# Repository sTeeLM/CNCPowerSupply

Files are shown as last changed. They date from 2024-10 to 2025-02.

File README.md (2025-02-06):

## 一个隔离四通道的数控+程控可调低波纹直流电源 ##
### 介绍 ###
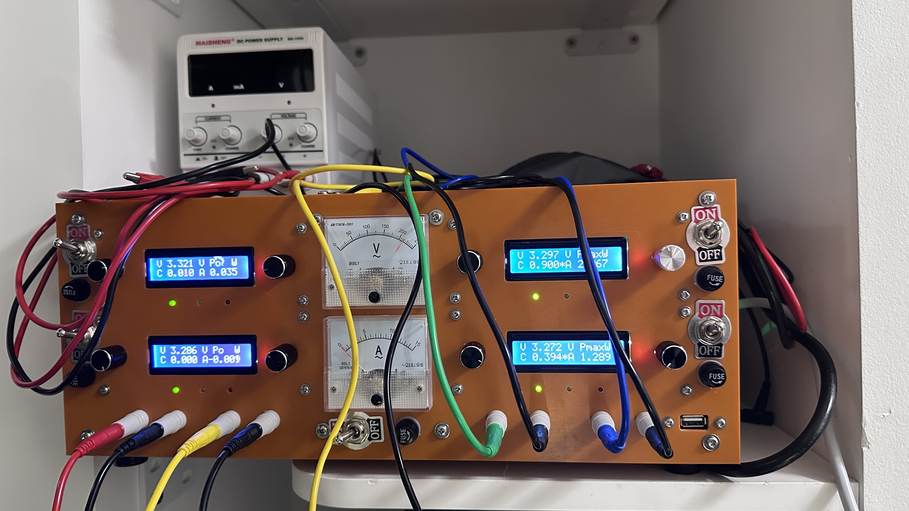
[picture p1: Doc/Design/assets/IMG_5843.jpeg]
完成图

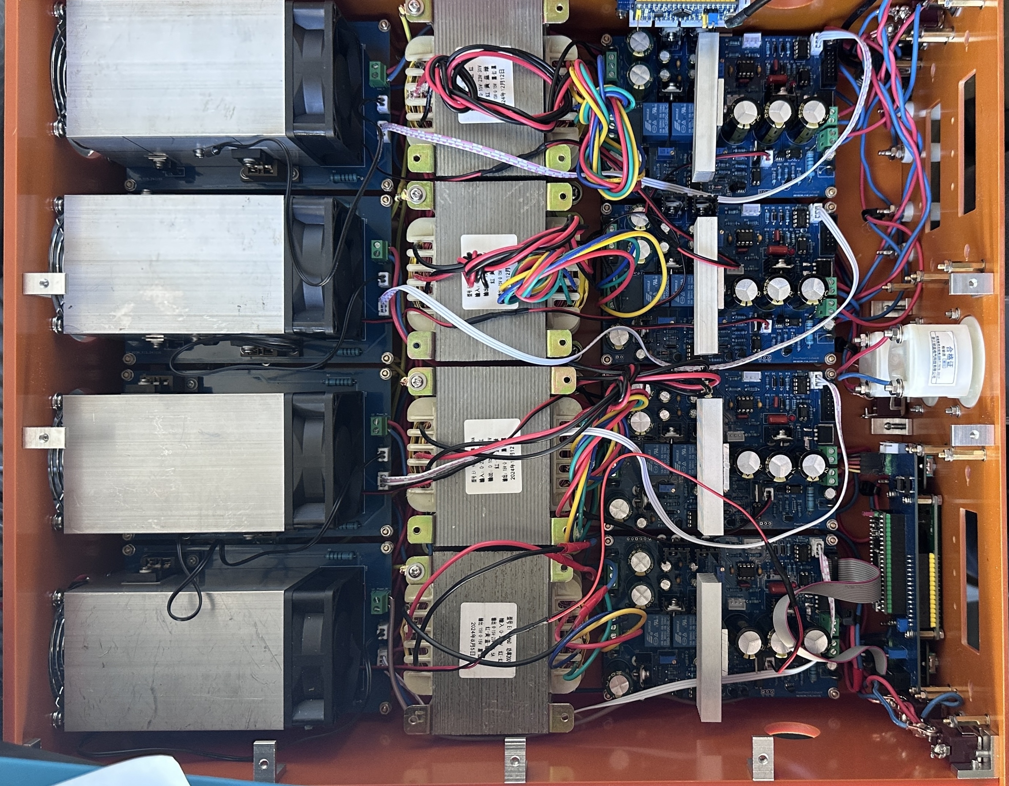
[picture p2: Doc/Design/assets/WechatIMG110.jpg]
内部构造


每通道最大输出电压30V，电流5A，波纹小于1mV，各通道独立可串联或者并联，可以通过USB远程用电脑程序化控制。
由于采用了原始的线性降压设计，带着4个200VA的变压器，加上外壳、散热器重量，所以很笨重。
外壳采用酚醛树脂制作，第一次折腾AutoCAD，加上审美不在线，做出来浓浓的苏联风。
成本量产500RMB以内，单个制作1000RMB左右，市面上类似电源一个2000～4000RMB不等。

### 主要功能 ###
1. 4路直流隔离，每路最大输出30V+5A，可长时间工作
2. 预设4挡电压电流值，可修改
3. 自动风扇控制，上下阈值可设置
4. 高耗散功率自动断开防烧毁
5. USB电脑远程控制和编程扩展
6. 在线校正和上位机校正

### TODO ###
1. 前置开关电源而不是变压器，以波纹换重量优化。
2. 完成USB上位机的控制程序，内嵌Python解释器。
3. 更好的校正设计甚至是自动校正。

## A CNC DC Power Supply with 4 independent channel ##
The maximum output voltage of each channel is 30V, the current is 5A, and the ripple is less than 1mV. all channels can be connected in series or parallel.
It can be programmed and controlled remotely via USB.
Because it uses an original linear step-down design with a 200VA transformer, it is extremely bulky. The shell is made of phenolic resin and has a strong Soviet style.

### TODO ###
1. use switching power supply plus linear convertor instead of the transformer for weight optimization.
2. Complete the control program on the USB host computer and embed the Python interpreter.
3. Better calibration design or even automatic calibration.

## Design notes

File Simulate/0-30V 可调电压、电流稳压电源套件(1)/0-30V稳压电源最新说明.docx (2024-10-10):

0-30V 可调电压、电流稳压电源安装使用说明书

这是一个高品质的连续可调稳压电源，电压调整范围为0-30V，还包含了一个电流输出限制电路，有效地控制最大输出电流从 2毫安到3安连续可调，这个特色让这个稳压电源成为电路实验不可或缺的利器， 它可以把电流限制在实验电路的典型最大工作电流，大胆地开启电源，不用担心因故障或安装错误造成大电流破坏实验电路。

技术规格：

输入电压：24V 交流（最大）

输入电流：3A（最大）

输出电压：0-30V 连续可调

输出限制电流：2mA-3A 连续可调

输出电压纹波：0.01%（最大）

电路特点：

全部直插元件，安装、维修简单方便；

输出电压易于调整；

输出电流限制状态由 LED 指示；

当输出电流超过限制电流时自动转为恒流模式， 对超负载或故障提供完全保护。

元件清单：

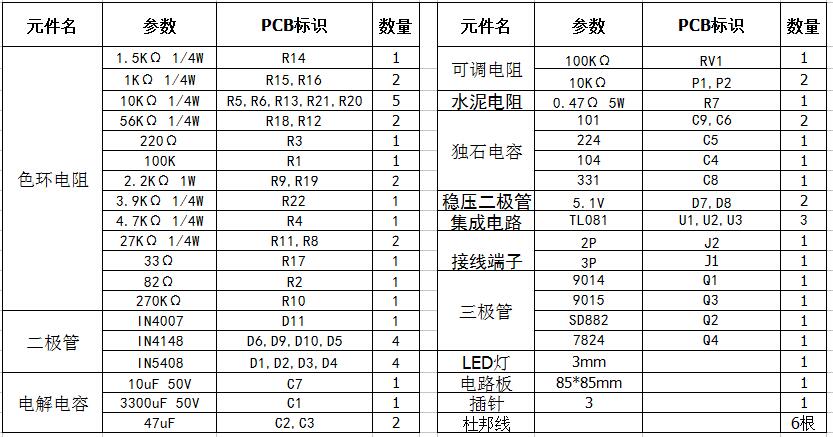
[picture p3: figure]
元件清单

安装步骤：

1.按照 PCB 标示安装电阻、二极管等，电阻安装前务必用万用表核对阻值确保正确，二极管注意型号、安装方向。

2. 依照从小到大、从低到高的原则安装其他元件。

3. 注意集成电路的安装方向，电位器可直接安装在板上， 也可用配套的插座及连线引到面板安装。

4.全部安装完毕，仔细检查无误后，即可通电试机，通电前务必确保 Q4（D1047）安装了足够大面积的散热片，散热片需与电路

绝缘

电路调整：

左边电位器用于电流调节，右边电位器用于电压调节。

1.将电压调整电位器设在最小位置(逆时针旋到最小) ，调整 RV1（100K 可调电阻） ，使输出电压为0V 即可（调整中可能会出现负电

压并且数值很小，请使用数字万用表进行） 。最大输出电压不需调整，使用 24V 交流输入时，最大输出电压约为 31V 左右。

2.电流标定：使用合适的负载电阻接在输出端，比如 10 欧（确保功率足够） ，电流电位器旋至最大，电压电位器旋至最小，开机

慢慢增加电压至 1V，逆时针调整电流电位器至发光管刚刚发亮，此时电路限制电流为 0.1A，标记下此时电位器的位置。依次调整至

2V、5V、10V、20V、30V 等数值，即可标定不同的输出电流，计算公式为：I=U/ R，如使用 10 欧负载，当 U 为 30V 时，I=3A

（最大输出） 。也可以换用其他阻值负载电阻，但务必注意功率足够并散热良好。

注意事项：

1.变压器输出电压为单 24V 或双 12V（中心头空置） ，功率可按需选择，如需满载输出（30V3A） ，变压器功率应在 90W 以上。

注意：本电路必须使用 24V 交流输入，不能使用直流输入。

2.输出调整管 D1047 安装散热器时需注意与电路绝缘，因本电路属于线性稳压电源， 调整管耗散功率比较大， 务必保证 D1047

散热良好。

3.电源制作属于大电流高电压电路，如安装有误可能造成危险，请务必认真核对元件型号并正确安装。

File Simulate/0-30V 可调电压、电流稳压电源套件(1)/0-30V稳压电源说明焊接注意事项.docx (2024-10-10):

0-30V 可调电压、电流稳压电源安装使用说明书

这是一个高品质的连续可调稳压电源，电压调整范围为0-30V，还包含了一个电流输出限制电路，有效地控制最大输出电流从 2毫安到3安连续可调，这个特色让这个稳压电源成为电路实验不可或缺的利器， 它可以把电流限制在实验电路的典型最大工作电流，大胆地开启电源，不用担心因故障或安装错误造成大电流破坏实验电路。

技术规格：

输入电压：24V 交流（最大）

输入电流：3A（最大）

输出电压：0-30V 连续可调

输出限制电流：2mA-3A 连续可调

输出电压纹波：0.01%（最大）

电路特点：

全部直插元件，安装、维修简单方便；

输出电压易于调整；

输出电流限制状态由 LED 指示；

当输出电流超过限制电流时自动转为恒流模式， 对超负载或故障提供完全保护。

元件清单：安装步骤：

元件清单
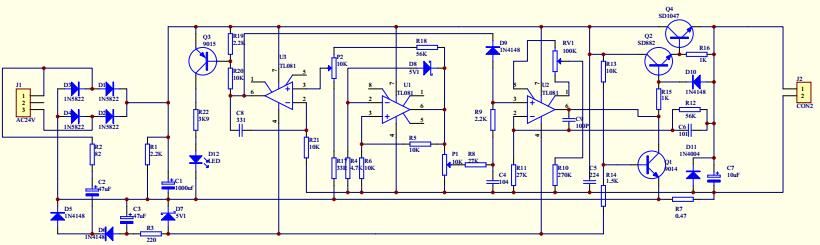
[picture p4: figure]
电路图

1.按照 PCB 标示安装电阻、二极管等，电阻安装前务必用万用表核对阻值确保正确，二极管注意型号、安装方向。

2. 依照从小到大、从低到高的原则安装其他元件。

3. 注意集成电路的安装方向，电位器可直接安装在板上， 也可用配套的插座及连线引到面板安装。

4.全部安装完毕，仔细检查无误后，即可通电试机，通电前务必确保 Q4（D1047）安装了足够大面积的散热片，散热片需与电路

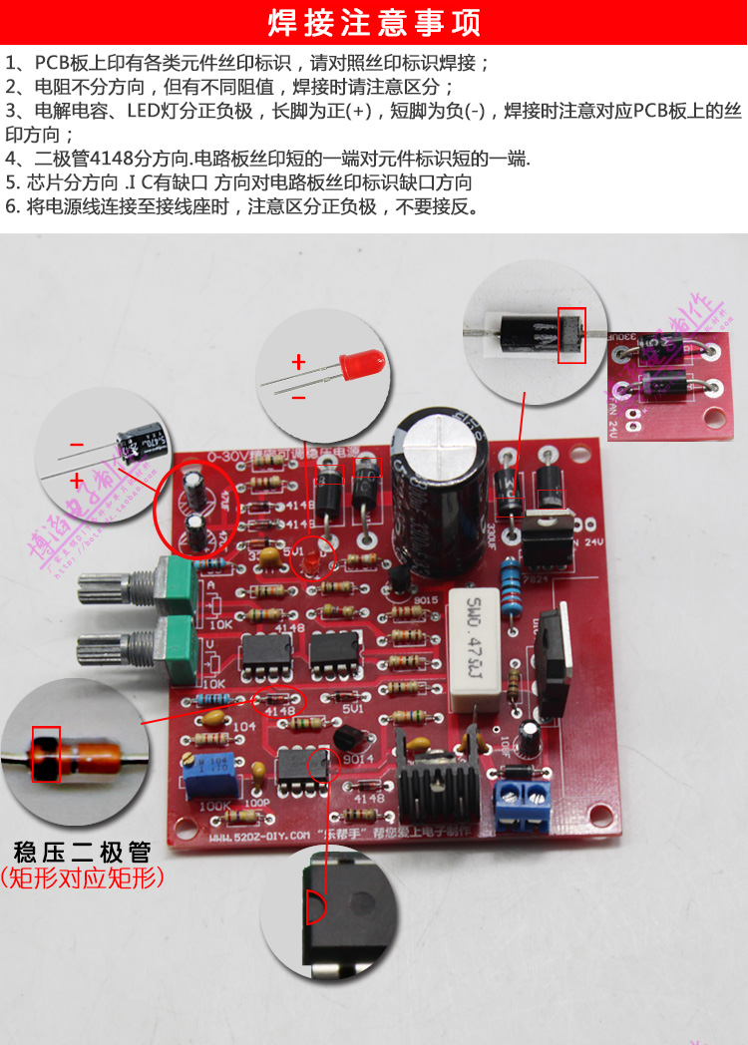
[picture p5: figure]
详情_06

绝缘

电路调整：

左边电位器用于电流调节，右边电位器用于电压调节。

1.将电压调整电位器设在最小位置(逆时针旋到最小) ，调整 RV1（100K 可调电阻） ，使输出电压为0V 即可（调整中可能会出现负电

压并且数值很小，请使用数字万用表进行） 。最大输出电压不需调整，使用 24V 交流输入时，最大输出电压约为 31V 左右。

2.电流标定：使用合适的负载电阻接在输出端，比如 10 欧（确保功率足够） ，电流电位器旋至最大，电压电位器旋至最小，开机

慢慢增加电压至 1V，逆时针调整电流电位器至发光管刚刚发亮，此时电路限制电流为 0.1A，标记下此时电位器的位置。依次调整至

2V、5V、10V、20V、30V 等数值，即可标定不同的输出电流，计算公式为：I=U/ R，如使用 10 欧负载，当 U 为 30V 时，I=3A

（最大输出） 。也可以换用其他阻值负载电阻，但务必注意功率足够并散热良好。

注意事项：

1.变压器输出电压为单 24V 或双 12V（中心头空置） ，功率可按需选择，如需满载输出（30V3A） ，变压器功率应在 90W 以上。

注意：本电路必须使用 24V 交流输入，不能使用直流输入。

2.输出调整管 D1047 安装散热器时需注意与电路绝缘，因本电路属于线性稳压电源， 调整管耗散功率比较大， 务必保证 D1047

散热良好。

3.电源制作属于大电流高电压电路，如安装有误可能造成危险，请务必认真核对元件型号并正确安装。

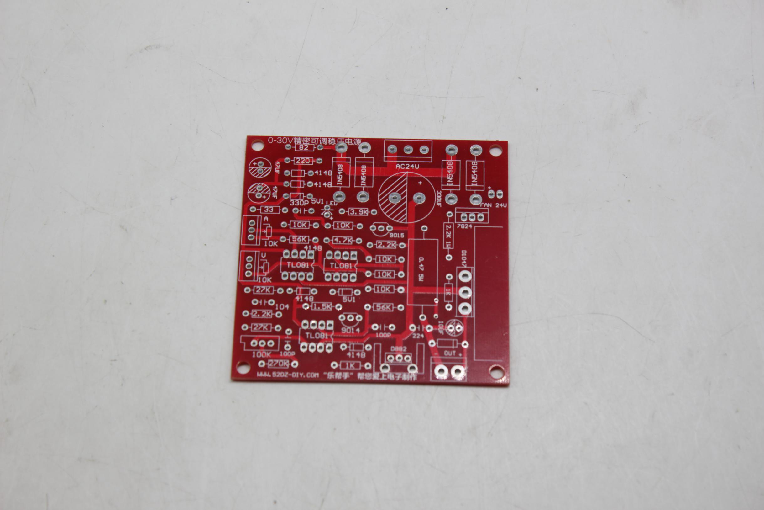
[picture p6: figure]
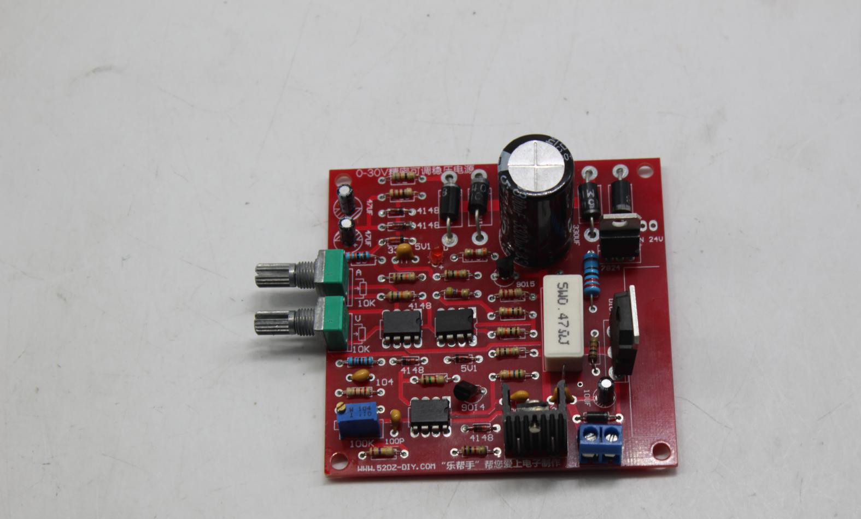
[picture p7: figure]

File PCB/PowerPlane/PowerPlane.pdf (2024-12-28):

Designator | Value | Name | Description | Quantity
C1, C6, C9, C10, C21 | 104 | | Capacitor | 5
C2, C13 | 471 | BBC | Capacitor | 2
C3, C8, C20 | 3300uF | 35V | Polarized Capacitor (Radial) | 3
C4, C7, C19 | 470uF | 25V | Polarized Capacitor (Radial) | 3
C5, C11 | 220uF | 16V | Polarized Capacitor (Radial) | 2
C12 | 153 | BBC | Capacitor | 1
C14 | 100uF | 50V | Polarized Capacitor (Radial) | 1
C15, C16, C17 | 2200uF | 63V | Polarized Capacitor (Radial) | 3
C18 | 47uF | 50V | Polarized Capacitor (Radial) | 1
D1 | | CC | Typical RED GaAs LED | 1
D2, D3, D10, D11 | | 1N5408 | 1 Amp General Purpose Rectifier | 4
D4, D5, D6, D7, D8, D9, D12, D13 | | 1N4007 | 1 Amp General Purpose Rectifier | 8
D14, D15 | | 1N4728 | Zener Diode | 2
Q1 | | TL431 | TL431 | 1
Q2 | | F4905S | P-Channel Power MOSFET | 1
Q3, Q5 | | TIP41 | NPN Bipolar Transistor | 2
Q4, Q6 | | S8550 | PNP Bipolar Transistor | 2
Q7 | | 2N5551 | NPN Bipolar Transistor | 1
Q8, Q9 | | S8050 | NPN Bipolar Transistor | 2
R1, R40, R41 | 2.7K | | Resistor | 3
R2, R24, R26 | 2K | | Resistor | 3
R3, R6, R10, R20, R21, R23, R28, R30, R37, R39, R45, R46 | 10K | | Resistor | 12
R4, R7, R8, R14, R15, R17, R43, R44 100R | | | Resistor | 8
R5 | 5K | | Potentiometer | 1
R9, R12 | 1M | | Resistor | 2
R11 | 6.8K | | Resistor | 1
R13, R27, R29 | 1K | | Resistor | 3
R16 | 3K | | Resistor | 1
R18, R36 | 100K | | Resistor | 2
R19 | 33K | | Resistor | 1
R22, R25 | 4.7K | | Resistor | 2
R31 | 330K | | Resistor | 1
R32 | 30K | 2W | Resistor | 1
R33 | 4.3K | 2W | Resistor | 1
R34 | 150K | | Resistor | 1
R35 | 56K | | Resistor | 1
R38, R42 | 10K | | Potentiometer | 2
U1, U9, U19 | | EL817C | EL817C | 3
U2, U22 | | L7812 | L7812 | 2
U3 | | L7805 | L7805 | 1
U4 | | TL082 | TL082 | 1
U5 | | LM393 | LM393 | 1
U6, U8 | | POT-3P | POT-3P | 2
U7 | | POWER3 | Power Connector 3 | 1
U10 | | L7912 | L7912 | 1
U11 | | L7905 | L7905 | 1
U12 | | POWER4 | Power Connector 3 | 1
U13, U14 | | SDR12VDCSLC | SDR12VDCSLC | 2
U15 | | FAN | FAN | 1
U16 | | KBU1010 | KBU1010 | 1
U17, U20 | | POWER2 | POWER2 | 2
U18 | | REG3 | REG2 | 1
U21 | | DC3-12P | DC3-12P | 1
U23 | | LM358 | LM358 | 1

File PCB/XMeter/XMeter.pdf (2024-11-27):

Line # | Designator | Value | Description | Quantity
| C1, C2, C6, C12, C15, C16, C18, C20, C22 | 104 | Capacitor | 9
| C3, C4, C7, C9 | 105 | Capacitor | 4
| C5, C11, C21 | 100uF | Polarized Capacitor (Radial) | 3
| C8, C10 | 226 | Capacitor | 2
| C13 | 474 | Capacitor | 1
| C14, C17, C19 | 106 | Capacitor | 3
| D1 | | 1 Amp General Purpose Rectifier | 1
| D2 | | Typical RED GaAs LED | 1
| D3 | | Typical RED GaAs LED | 1
| D4 | | Typical RED GaAs LED | 1
| Q1 | | PNP Bipolar Transistor | 1
| R1, R2, R21, R23, R24, R25 | 10K | Resistor | 6
| R3, R4, R18 | 0R | Resistor | 3
| R5 | 10K | Potentiometer | 1
| R6, R8, R15, R16 | 47K | Resistor | 4
| R7 | 43K | Resistor | 1
| R9, R11 | 20K | Resistor | 2
| R10 | 150K | Resistor | 1
| R12, R13, R14, R22 | 4.7K | Resistor | 4
| R17 | 270K | Resistor | 1
| R19 | 1K | Potentiometer | 1
| R20 | 30K | Resistor | 1
| R26 | 100 | Resistor | 1
| R27, R28, R29 | 1K | Resistor | 3
| U1 | | REF5020 | 1
| U2 | | REF5025 | 1
| U3, U4 | | DAC8571 | 2
| U5, U9 | | OPA2335 | 2
| U6 | | REF3230 | 1
| U7 | | LCD1602 | 1
| U8 | | DC3-12P | 1
| U10 | | STC89C516CORE | 1
| U11 | | CODEKEY | 1
| U12 | | ADS1115 | 1
| U13 | | BEEPER | 1
| U14 | | CODEKEY | 1
| U15 | | SG3030CM | 1
| U16 | | SERIAL4P | 1
| U17 | | AT24C02 | 1

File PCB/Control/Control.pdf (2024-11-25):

Line # | Designator | Value | Name | Description | Quantity
| D1 | | CN0 | Typical RED GaAs LED | 1
| D2 | | CN2 | Typical RED GaAs LED | 1
| D3 | | CN1 | Typical RED GaAs LED | 1
| D4 | | CN3 | Typical RED GaAs LED | 1
| R1, R2, R3, R4 | 1K | | Resistor | 4
| R5 | 0R | 500mA Fuse | Resistor | 1
| R6 | 10K | | Resistor | 1
| R7, R8 | 20R | | Resistor | 2
| U1, U3, U5, U7 | | ISO6721B | ISO6721B | 4
| U2, U4, U6, U8 | | SERIAL4P | SERIAL4P | 4
| U9 | | STM32F103CCORE | STM32F103CCORE | 1
| U10 | | USB-X254 | USB-X254 | 1
| U11 | | 74HC4052 | 74HC4052 | 1
| U12 | | CTLDBG | CTLDBG | 1

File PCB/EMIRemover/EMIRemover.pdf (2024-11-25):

Line # | Designator | Value | Name | Description | Quantity
| R1, R5, R6 | | 10D431K | 10D431K | 3
| R2, R4, R7 | | B5G600L | B5G600L | 3
| C1, C4 | 472 | 400V | Capacitor | 2
| C2, C3, C5 | 474 | 275V | Capacitor | 3
| U1, U2 | | HB9500-3P | HB9500-3P | 2
| R3 | 560K | 2W | Resistor | 1
| L1, L2 | | SQ3324/15A/10mH | SQ3324 | 2

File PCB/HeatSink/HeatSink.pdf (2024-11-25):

Line # | Designator | Value | Name | Description | Quantity
| Q1, Q2 | | TIP3055 | NPN Bipolar Transistor | 2
| U1 | | NTC | NTC | 1
| U2 | | POWER2 | POWER2 | 1
| U3 | | REG3 | REG2 | 1
| R1, R2 | 200 | 1W | Resistor | 2
| R3, R4 | 0.22R | 5W | Resistor | 2
| R5 | 0.4R | 35W | Resistor | 1

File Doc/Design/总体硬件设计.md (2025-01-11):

## 关键问题以及解决思路

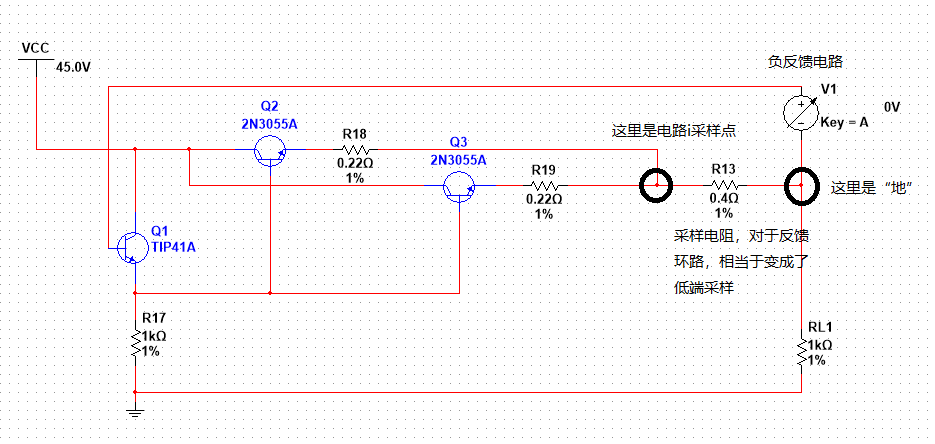
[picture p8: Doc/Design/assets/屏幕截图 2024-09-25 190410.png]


通过一段时间的实践（折腾），研究了很多参考设计，体会到一个可调线性电源，面临的核心设计问题是：
- 反馈运放需要对调整三极管输出足够高的，接近输出电压的高压来让调整三级管正常工作，从而选型困难或者设计复杂或者贵（> 44V的很少了，同时很难做到即要高压同时又要高精密）
- 如果采用性能更好的高端电流采样（低端采样，采样电阻在地一侧，输出电压会有误差），需要引入仪表放大器，、差分放大器又让设计变得更复杂，同时反馈环路引入放大器很容易不稳定
- 调整三极管耗散功率在输入输出电压差很高时，不可接受（烧毁）

问题1、2解决思路如上图（其中为了说明思路，用可变电压源代替电压反馈环和电流反馈环），反馈控制电路整个“架在”高端，输出电压的高端变成了反馈控制电路的地，反馈输出一个小控制电压，叠加在大的输出电压上作为整个反馈，这样完全不需要任何高压运放和高压仪表放大器之类的器件，用低端器件就可以搭（反馈输出参考地是输出电压高端，所以只需要正负几V、非轨到轨的运放都能用），由于降低了运放的电压要求，我们可以找到又便宜，精度又高的器件来用。同时电流采样和反馈很直观和简单，原来复杂的宽范围可变的高共模电压下电流采样电阻两端差分电压精确测量问题，变成了非常简单的对地测采样电阻的电压问题，唯一缺点是电压反馈就变得更稍微复杂一些，因为对运放来讲要求输入电压接近地并且大于地，而对输出电压直接采样的话，无论如何都做不到（采样结果一定小于输出电压，也就是地）。当然也可以加一个反向放大器，让负电压变正电压，但是在反馈环路中加放大器，是个需要很小心的事情，一不小心就震荡了。

这个缺点的克服方法非常巧妙，我们把输出电压加一个小的（本设计是2.5V）参考电压偏移，然后再做电压采样，巧妙的构造一个负反馈环：深度负反馈时候，根据虚短，可以得知(x+2.5)b=x+c，对，你没看错，采样反馈加在运放的正输入而不是负输入

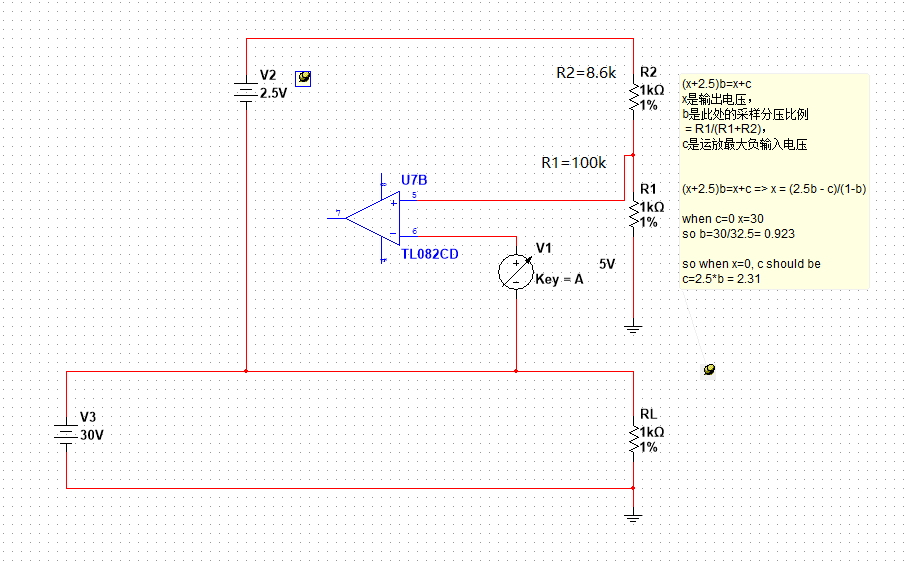
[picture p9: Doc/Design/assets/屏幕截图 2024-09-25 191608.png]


问题3的解决思路，是根据输出电压自动分段选择输入电压，在输出电压较低时候采用较低的输入电压，从而降低输入输出的压差和耗散功率，减少发热，我们直接采用2个继电器来切换各档输入电压。

## 总体硬件设计

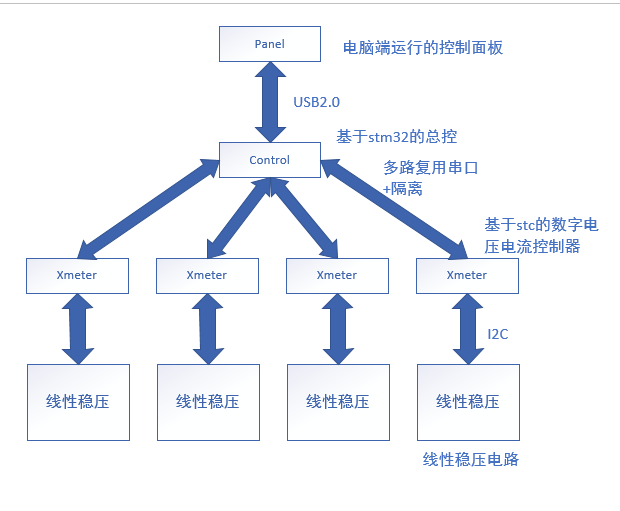
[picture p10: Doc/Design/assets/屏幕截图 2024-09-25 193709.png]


剩下的工作，无非是简单的嵌入式设计，只需要简单的数电基础，C语言写写程序，用AutoCAD设计下外壳（我们用成本更低的电木板材拼接，不用3D打印，整个外壳制造过程就是板材上钻孔，尽量避免铣槽，降低成本）

从单通道扩展到多通道很简单粗暴，如上图直接复制四份，然后加一个总控，每一个channel之间做好直流隔离就好（直接用4套变压器，并且和总控的串口通讯通过隔离芯片），从而这四个channel可以串联用、并联用。
在极低波纹下，可以达到600W的输出功率，拼出最高120V乘5A或者30V乘20A的输出。

做4路还有一个好处是，可以同时提供多种不同的电压输出，极大方便了我们调试各种板子（例如同时提供3.3\5V\正负12V这样的组合，直接给电脑主板供电）。

数控意味着可以在panel处通过电脑连USB控制4路电源，甚至使用程序扩展（例如写一段锂电池充电程序，先恒流再恒压等等）

## 选型

为啥XMeter用8051（STC的），总控用STM32，就是因为这两个片子我屯多了，没有经过仔细的考虑，就是手里有什么用什么。

## 制作后体会 ##
1. 模电基本功很重要，不少坑都踩在基本功上，无论是运放一不小心就震荡，还是MOS打开电压过低就会内阻狂飙，还是三极管工作参数的计算、二极管的各种骚操作，电阻电容延时时间的计算，这些东西比数电有趣太多了。
2. 设计一时爽，制造火葬场：面向制造环节的各种要素（可测性、量产、成本等）做设计才是真正有挑战的地方，细节众多，迭代慢，不是很确定是不是真的可以AI搞定一切。跨领域知识储备要求也很高，要在这些既跨领域，又依赖的要素之间做权衡，对知识的深度和精确度，以及复杂问题解决能力都是很高的挑战。如果训练模型的话，怎么把一个一个经验case（特别是怎么排查故障）都总结成样本，可能是最难的吧。
设计一时爽，制造火葬场的另一层含义是，小制作都是打样很爽，批量制造是个体力活，我不喜欢重复性工作，本质上是手工焊接做4套电源，焊四遍，每遍4张PCB，还需要手工拧螺丝、接线组装焊好的PCB板和其它杂碎零件，更别提各种故障排查了。
4. 基本原则一定要遵守、一定要养成好习惯，例如：
* 做好面包板、焊好PCB上电前，一定检查焊点和元件位置，有插槽检查插槽。
* 上电前一定用万用表打一下VCC和地。
* 上电异常，断电后没有追到原因，排除问题之前坚决不能再次上电，"试一试"都不要。
* 追查问题一定从最简单猜测开始追，先检查基础假设。
* 凡有反常必有妖，不符合预期一定要追查到底。

基本上本次制作过程中所有翻过的车，踩过的坑，白白烧掉的元件，浪费的时间和返工，如果严格遵守上述5条，99%都可以避免。

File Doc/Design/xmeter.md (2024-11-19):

## 交互总体原则 
1. 交互符合直觉，逻辑前后尽量一致（我也曾经是个产品经理。。）  
两个按钮的用法，尽量按照符合直觉操作习惯设计  
1. mod：短按是模式切换，旋转是电压调整、数值粗调  
1. set：短按是数值选定，旋转是电流调整、数值精调  
1. 长按是特殊功能  

## 事件
|名称|含义|
|--|--|
250ms| 时钟脉冲250ms
1s| 时钟脉冲1s
Mu|Mod Up  
Md| Mod Down  
Ms| Mod Short Press  
Ml| Mod Long Press  
Mc| Mod Clock wise  
Mcc| Mod Counter Clock wise  
Su| Set Up  
Sd| Set Down  
Ss| Set Short Press  
Sl| Set Long Press  
Sc| Set Clock wise  
Scc| Set Counter Clock wise  
MSs| Mod+Set Press  
MSl| Mod+Set Long Press  
OVER_HEAT|过热  
OVER_PD|过载  
TEMP_HI| 温度超过阈值  
TEMP_LO| 温度低于阈值  
EV_TIMEO| 超时  

## 功能1 XMeter
**主功能，电压、电流、功率、温度显示、设置、过载保护**
### Main
**显示V、C、P**
|事件|动作|
|--|--|
Ms|进入PickV  
Ss|进入PickC  
Ml|进入Aux0  
Sl|进入Param功能  
MSs|进入校准功能  
Mc/Mcc|进入SetV  
Sc/Scc|进入SetC  
250ms|从ADC更新一遍计数并刷新LCD  
OVER_HEAT|关闭电源，打开风扇，进入OverHeat  
OVER_PD|关闭电源，进入OverPd  
TEMP_HI|开风扇  
TEMP_LO|关风扇  

### Aux0
**显示Vi、Pd**
|事件|动作|
|---|---|
250ms|从ADC更新一遍计数并刷新LCD  
Ms| 回到Main  
EV_TIMEO| 回到Main  
Mc/Mcc| Aux0/Aux1切换  
Sc/Scc| Aux0/Aux1切换  
OVER_HEAT| 关闭电源，打开风扇，进入OverHeat  
OVER_PD| 关闭电源，进入OverPd  
TEMP_HI| 开风扇  
TEMP_LO|关风扇  

### Aux1
**显示T、Fan**
|事件|动作|
|---|---|
250ms| 从ADC更新一遍计数并刷新LCD
Ms| 回到Main
EV_TIMEO| 回到Main
Mc/Mcc| Aux0/Aux1切换
Sc/Scc| Aux0/Aux1切换
OVER_HEAT| 关闭电源，打开风扇，进入OverHeat
OVER_PD| 关闭电源，进入OverPd
TEMP_HI| 开风扇
TEMP_LO|关风扇

### PickPreV
**选择预设置电压**
|事件|动作|
|---|---|
250ms| 从ADC更新一遍计数并刷新LCD
Mc/Mcc| 切换预设电压
Ms| 设置预设电压并返回Main **特殊不符合约定的设计，但是更符合直觉**
OVER_HEAT| 关闭电源，打开风扇，进入OverHeat
OVER_PD| 关闭电源，进入OverPd
TEMP_HI| 开风扇
TEMP_LO| 关风扇
EV_TIMEO| 放弃设置回到Main

### PickPreC
**选择预设值电流**
|事件|动作|
|---|---|
250ms| 从ADC更新一遍计数并刷新LCD
Sc/Scc| 切换预设电流
Ss| 设置预设电流并返回Main
OVER_HEAT| 关闭电源，打开风扇，进入OverHeat
OVER_PD| 关闭电源，进入OverPd
TEMP_HI| 开风扇
TEMP_LO|关风扇
EV_TIMEO| 放弃设置回到Main

### SetV
**设置电压**
|事件|动作|
|---|---|
250ms| 从ADC更新一遍计数并刷新LCD
Mc/Mcc| 粗粒度设置电压（100mV）
Sc/Scc| 细粒度设置电压（小数最末有效数字，最小1mV）
Ms| 设置预设电压并返回Main
EV_TIMEO| 放弃设置回到Main
OVER_HEAT| 关闭电源，打开风扇，进入OverHeat
OVER_PD| 关闭电源，进入OverPd
TEMP_HI| 开风扇
TEMP_LO|关风扇

### SetC
**设置电流**
|事件|动作|
|---|---|
250ms| 从ADC更新一遍计数并刷新LCD
Mc/Mcc| 粗粒度设置电流（100mA）
Sc/Scc| 细粒度设置电流（小数最末有效数字，最小1mA）
Ss| 设置预设电流并返回Main
EV_TIMEO| 放弃设置回到Main
OVER_HEAT| 关闭电源，打开风扇，进入OverHeat
OVER_PD| 关闭电源，进入OverPd
TEMP_HI| 开风扇
TEMP_LO| 关风扇

### OverHeat
**过热状态**
|事件|动作|
|---|---|
250ms| 从ADC更新一遍计数并刷新LCD
Ss| 开始一次检测，如果温度低于TEMP_LO发送EV_TIMEO消息
EV_TIMEO| 打开电源并回到Main
TEMP_HI| 开风扇
TEMP_LO| 关闭风扇

### OverPd
**过载状态**
|事件|动作|
|---|---|
250ms| 从ADC更新一遍计数并刷新LCD
Ss| 打开电源并回到Main
TEMP_HI| 开风扇
TEMP_LO| 关闭风扇

## 功能2 参数设置 Set Param
> 辅助功能，设置各种参数，交互逻辑是分为4个大功能块  
> 每个功能块入口都可以通过Sl回到XMeter主界面  
> 功能块入口Ms切换功能块，Ss数值设置  
> 这样设计本质是把一个大的平铺线性向导，分割成了几个子向导  
> 避免了一次设置必须要全部经过一遍的囧境  
1. 保护相关的参数设置
2. 预设电压
3. 预设电流
4. 其他杂项参数
### Fan（功能块入口1）
**风扇温度上下限**
|事件|动作|
|---|---|
Mc/Mcc| 开启温度上限（以0.5 C）
Sc/Scc| 关闭温度下限（以0.5 C）
Ss| 设置温度上下限，并进入OverProtect
Ms| 进入SelPreV
Sl| 回到Main

### 过载保护OverProtect
**过载保护温度和功率**
|事件|动作|
|---|---|
Mc/Mcc| 过载保护温度（以0.5 C）
Sc/Scc| 最大耗散功率（以0.5 w）
Ss|  设置参数，并回到Fan

### SelPreV（功能块入口2）
**切换预设电压**
|事件|动作|
|---|---|
Mc/Mcc| 切换预设电压index
Sc/Scc| 切换预设电压index
Ss| 选定index并进入SetPreV
Ms| 进入SelPreC

### SetPreV
**设置预设电压**
|事件|动作|
|---|---|
Mc/Mcc| 粗调电压（100mV）
Sc/Scc| 精调电压（小数最末有效数字，最小1mV）
Ss| 设置并回到SelPreV

### SelPreC （功能块入口3）
**切换预设电流**
|事件|动作|
|---|---|
Mc/Mcc| 切换预设电流index
Sc/Scc| 切换预设电流index
Ss| 选定index进入SetPreC
Ms| 进入Beeper

### SetPrevC
**设置预设电流**
|事件|动作|
|---|---|
Mc/Mcc| 粗调电流（100mV）
Sc/Scc| 精调电流（小数最末有效数字，最小1mA）
Ss| 设置并回到SelPreC

### Beeper （功能块入口4）
**开关Beeper**
|事件|动作|
|---|---|
Mc/Mcc| Beeper On/Off切换
Mc/Mcc| Beeper On/Off切换
Ss| 设置Beeper并进入Fan设置
Ms| 回到Fan，但是不保存设置

## 功能3 Calibration
**辅助功能，校准功率平面的零值和最大值**
**过载保护功能完全关闭**
**风扇完全关闭**
三个阶段：  
1. 物理调整（手工）
2. 参数标定（手工）
3. 参数计算（自动）
阶段1可调节的几个物理电位器:  
- A. 电压反馈分压电位器(控制电压最大值)
- B. 两个三段电压继电器对应的电位器（控制2个切换输入电压）
### CalPhyVoltage
**电压物理调整，调整目标**
- 三段电压继电器正常工作（调节B）
- 电压DAC在0xFFFF对应输出30V（调节A，在0x0000可能输入的是负数，没关系）
- 用笔记录在输出0V的时候，输入电压万用表读数

|事件|动作|
|---|---|
Mc/Mcc| 粗调电压电位器读数（16LSB）
Sc/Scc| 精调电压电位器读数（1LSB）
Ss| 切换到CalVoltageZero
### CalVoltageZero
**标定输出电压零点**
- 调整到电压输出0V，按下Ss

|事件|动作|
|---|---|
Mc/Mcc| 粗调电压电位器读数（16LSB）
Sc/Scc| 精调电压电位器读数（1LSB）
Ss| 记录输出电压0点时的ADC参数（和*耗散电压ADC参数*），切换到CalVoltageMax
### CalVoltageMax
**标定输出电压最大值**
- 调整到电压输出30V，按下Ss

|事件|动作|
|---|---|
Mc/Mcc| 粗调电压电位器读数（16LSB）
Sc/Scc| 精调电压电位器读数（1LSB）
Ss| 记录输出电压最大点参数，*电压DAC设置为5V输出档*，切换到CalCurrentZero
### CalCurrentZero
**标定输出电流零点**
- 短路输出，调整到电流输出0A，按下Ss

|事件|动作|
|---|---|
Mc/Mcc| 粗调电流电位器读数（16LSB）
Sc/Scc| 精调电流电位器读数（1LSB）
Ss| 记录输出电流为0时的参数(电流DAC)，切换到CalPhyCurrentMax
### CalCurrentMax
**标定输出电流最大值**
- 短路输出，调整到电流输出5A，按下Ss

|事件|动作|
|---|---|
Mc/Mcc| 粗调电流电位器读数（16LSB）
Sc/Scc| 精调电流电位器读数（1LSB）
Ss | 记录输出电流为5A时的参数(电流DAC)，切换到InputVoltageDiss
### InputVoltageDiss
**输入耗散电压读数**
- 输入耗散电压读数
Mc/Mcc| 粗调电压输入（100mV）
Sc/Scc| 精调电压读数（1mV）
Ss | 记录输出电压为0时的耗散电压读数参数(从万用表)，切换到CalBK
### CalBK
**自动校准耗散电压ADC和电流ADC，以及输出电压ADC**
|事件|动作|
|---|---|
1s |依次校准，如果完成, 写入rom
Ss | 如果校准完成或者失败发送EV_TIMEO
EV_TIMEO| 回到XMeter.main

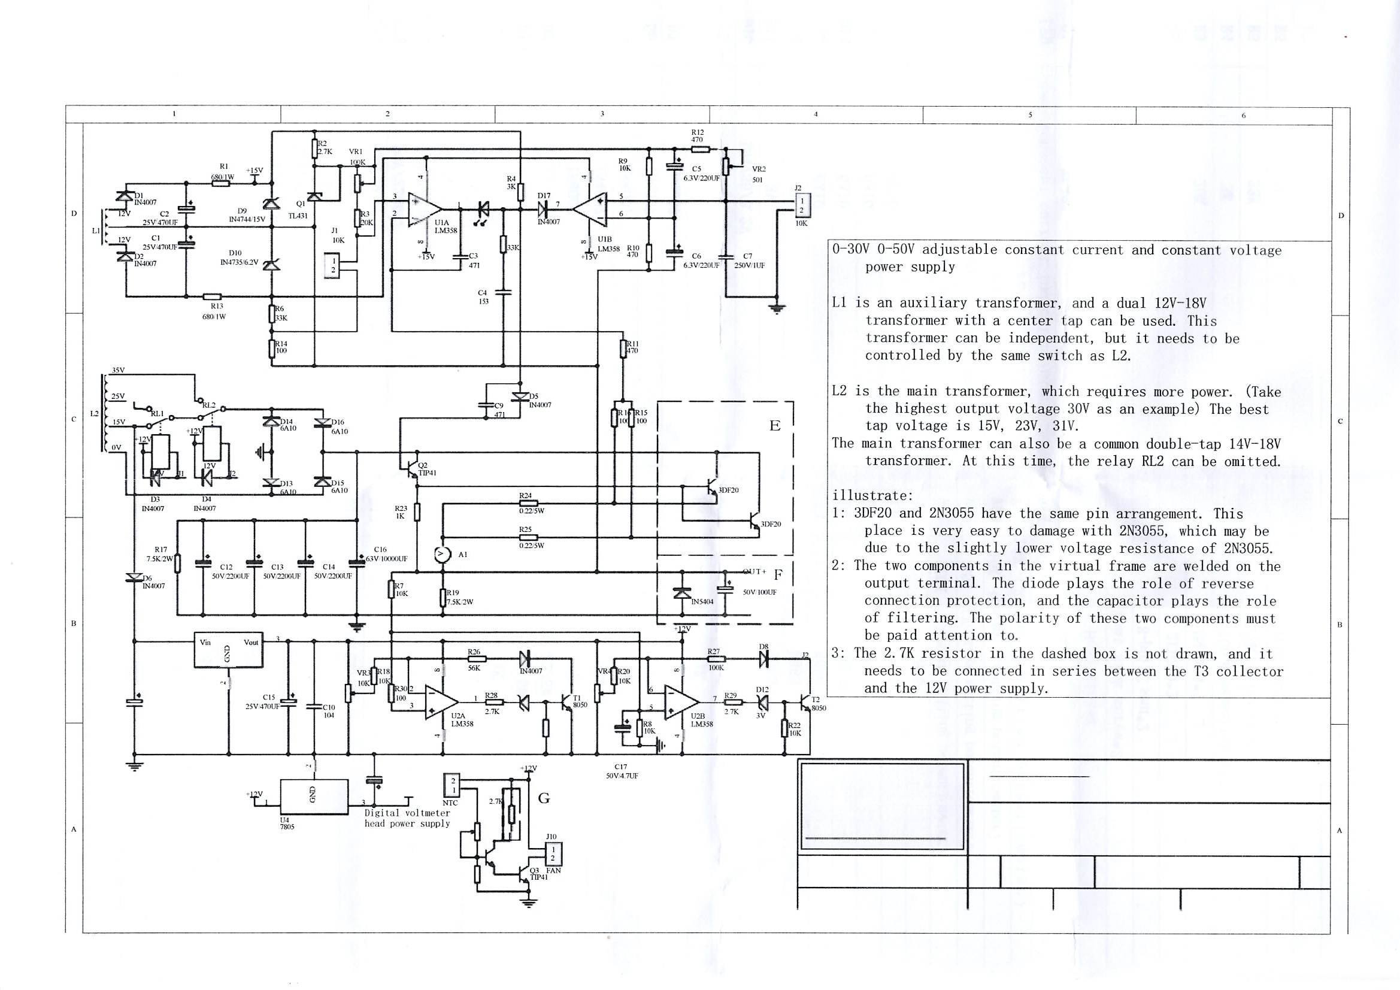
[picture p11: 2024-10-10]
Simulate/0-30V 可调电压、电流稳压电源套件(2)/EPSON019.JPG

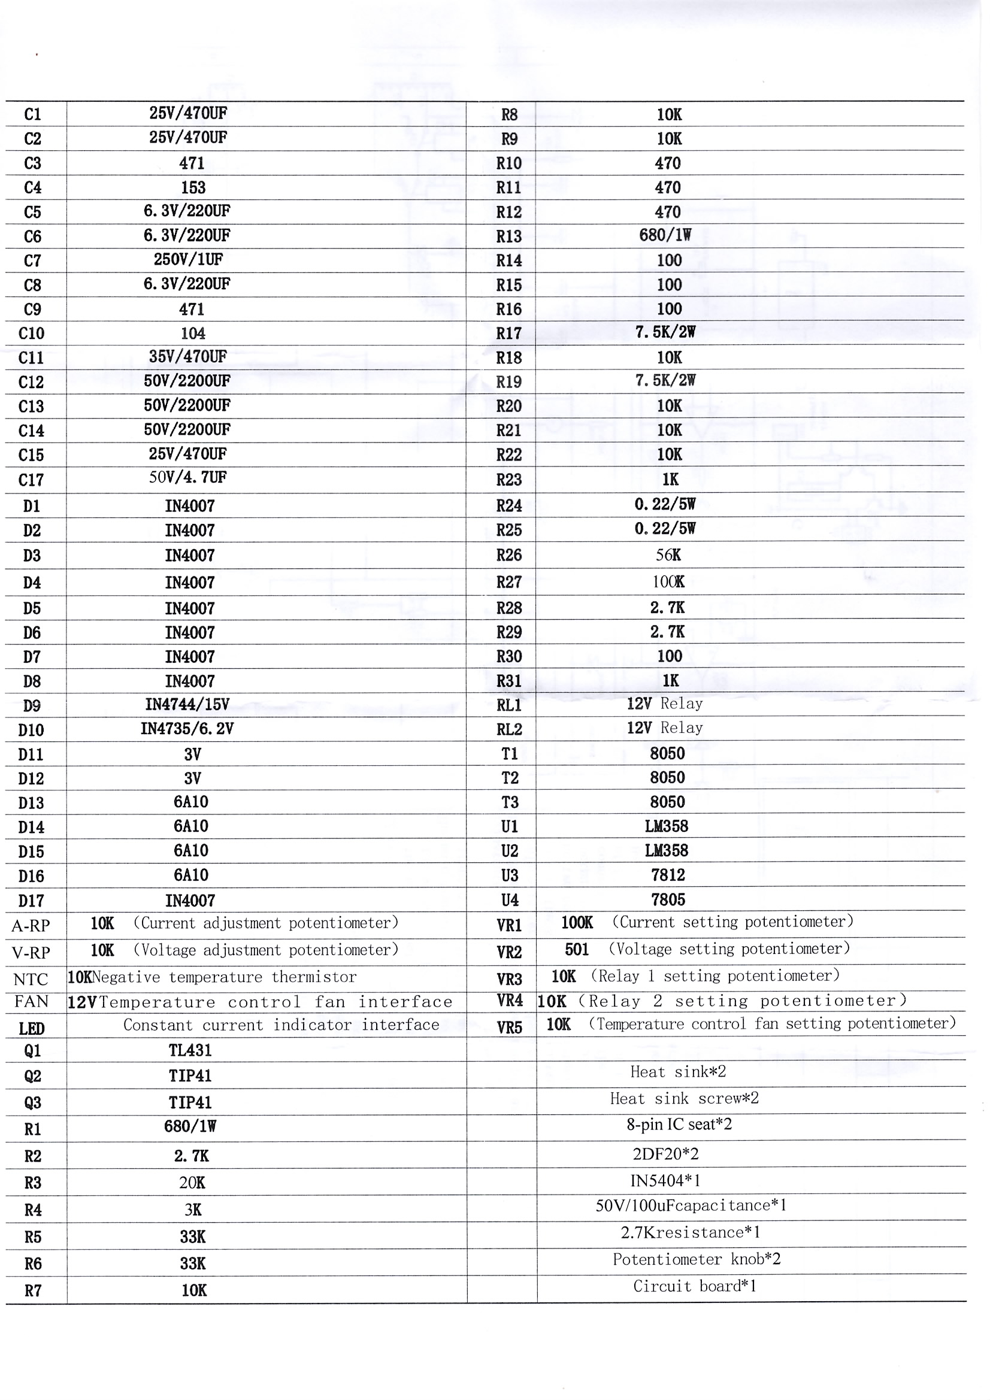
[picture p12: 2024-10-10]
Simulate/0-30V 可调电压、电流稳压电源套件(2)/EPSON020.JPG

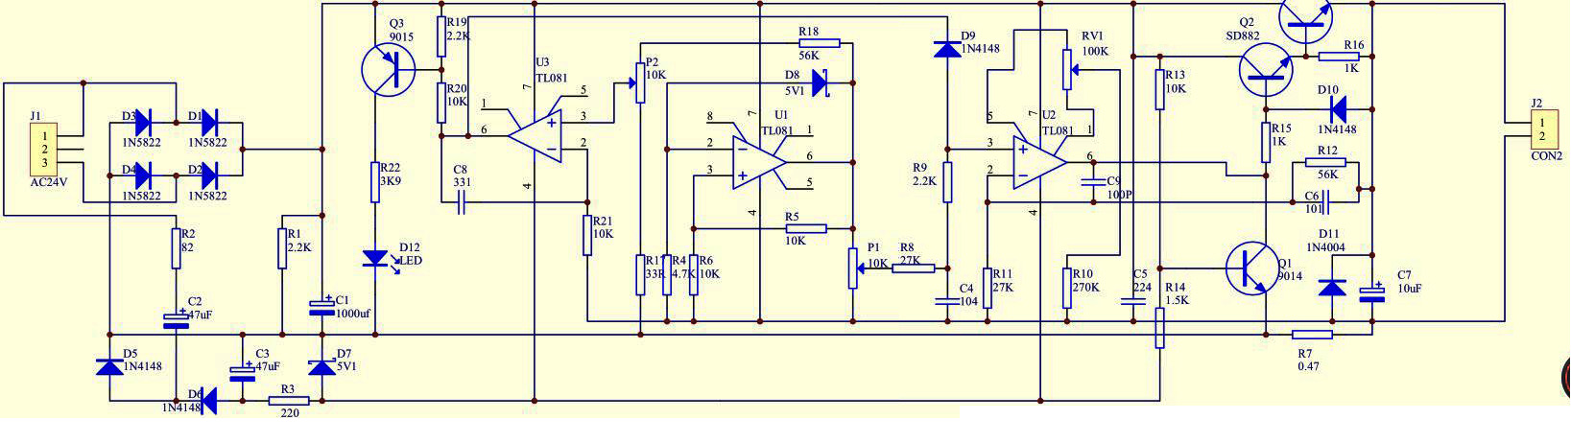
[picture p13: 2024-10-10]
Simulate/0-30V 可调电压、电流稳压电源套件(1)/1电路图.JPG

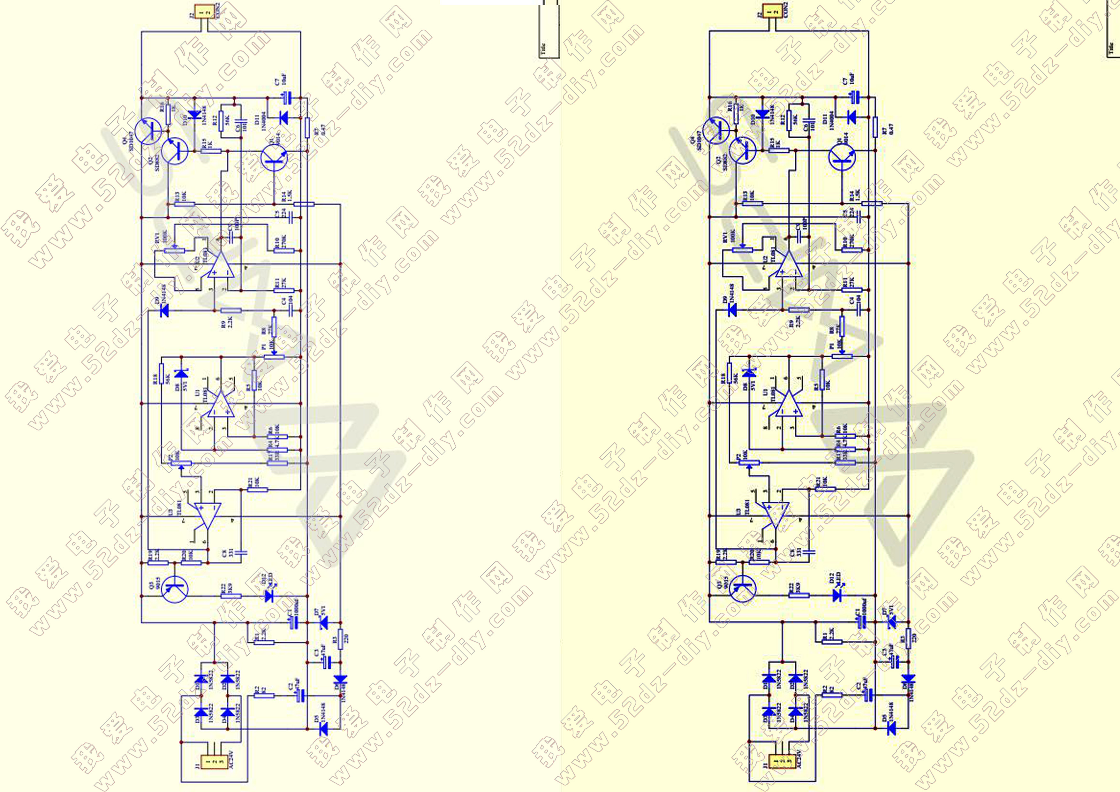
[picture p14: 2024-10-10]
Simulate/0-30V 可调电压、电流稳压电源套件(1)/0-30V 可调电压、电流稳压电源套件说明书2.jpg

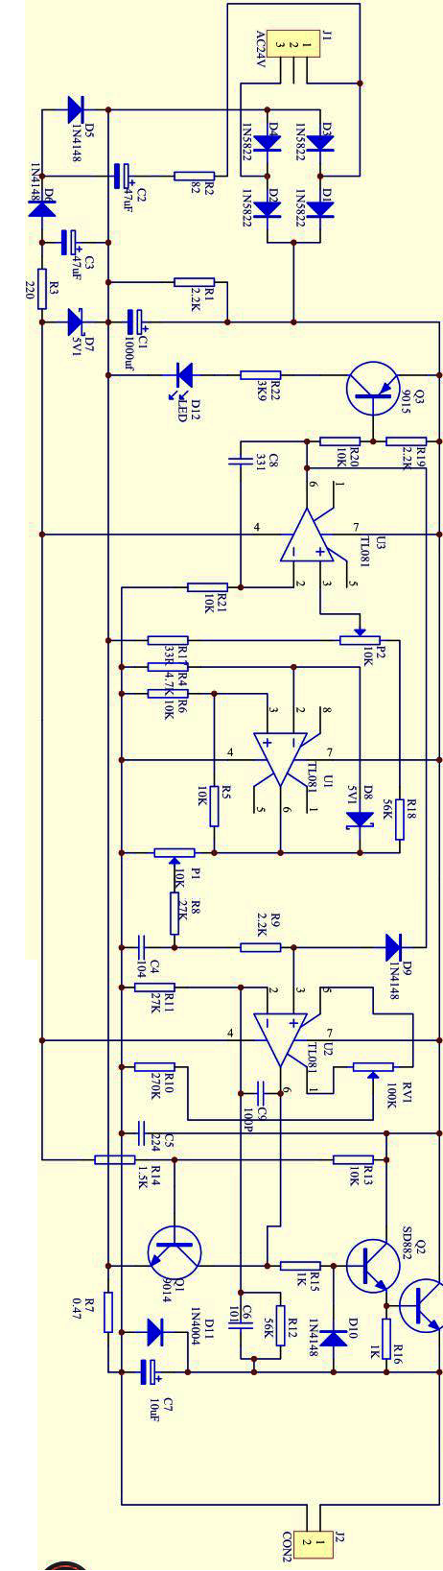
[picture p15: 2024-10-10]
Simulate/0-30V 可调电压、电流稳压电源套件(1)/2电路图.PNG

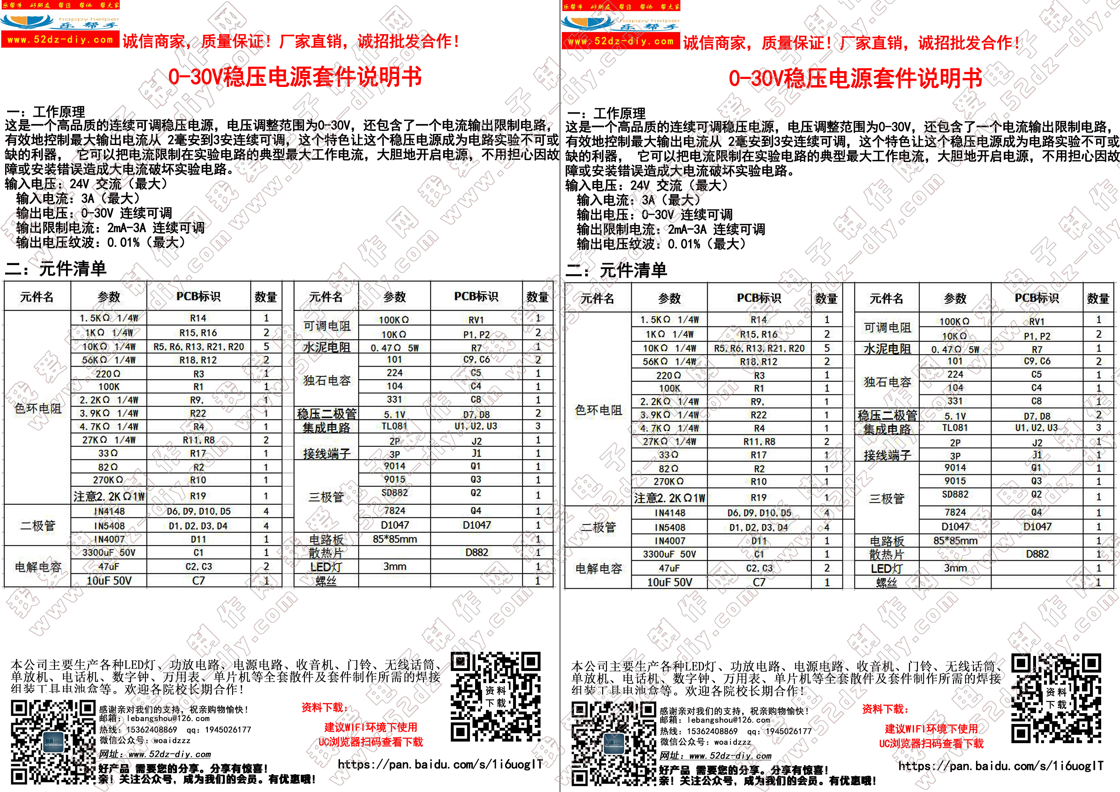
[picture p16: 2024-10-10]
Simulate/0-30V 可调电压、电流稳压电源套件(1)/0-30V 可调电压、电流稳压电源套件说明书.JPG

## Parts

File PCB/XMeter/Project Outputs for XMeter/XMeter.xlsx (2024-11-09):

Line # | Designator | Value | Name | Description | Quantity
1 | C1, C2, C3, C4, C6, C8, C9, C12, C13, C14, C15, C16 | 104 |  | Capacitor | 12
2 | C5, C7 | 10uF | 16V | Polarized Capacitor (Radial) | 2
3 | C10, C11 | 100uF | 16V | Polarized Capacitor (Radial) | 2
4 | D1 |  | SS12 | 1 Amp General Purpose Rectifier | 1
5 | D2 |  | SWITCH | Typical RED GaAs LED | 1
6 | D3 |  | FAN | Typical RED GaAs LED | 1
7 | D4 |  | CC | Typical RED GaAs LED | 1
8 | Q1 |  | S8550(2TY) | PNP Bipolar Transistor | 1
9 | R1 | 91K |  | Resistor | 1
10 | R2, R6, R10, R11 | 40K |  | Resistor | 4
11 | R3, R4, R5, R12 | 4.7K |  | Resistor | 4
12 | R7 | 1K |  | Potentiometer | 1
13 | R8 | 14K |  | Resistor | 1
14 | R9, R16 | 10K |  | Resistor | 2
15 | R13 | 120K |  | Resistor | 1
16 | R14 | 5K |  | Potentiometer | 1
17 | R15, R24 | 0R |  | Resistor | 2
18 | R17 | 100 |  | Resistor | 1
19 | R18, R19, R20 | 10k |  | Resistor | 3
20 | R21, R22, R23 | 1K |  | Resistor | 3
21 | U1 |  | CODEKEY(MOD) | CODEKEY | 1
22 | U2 |  | LCD1602 | LCD1602 | 1
23 | U3 |  | CODEKEY(SET) | CODEKEY | 1
24 | U4 |  | LT1990 | LT1990 | 1
25 | U5, U7 |  | OPA2335 | OPA2335 | 2
26 | U6 |  | STC89C516CORE | STC89C516CORE | 1
27 | U8 |  | BEEPER | BEEPER | 1
28 | U9 |  | SG3030CM | SG3030CM | 1
29 | U10 |  | ADS1115 | ADS1115 | 1
30 | U11 |  | DC3-12P | DC3-12P | 1
31 | U12 |  | MAX660 | MAX660 | 1
32 | U13 |  | SERIAL4P | SERIAL4P | 1
33 | U14 |  | AT24C02 | AT24C02 | 1

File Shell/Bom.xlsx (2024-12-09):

分类 | 编号 | 名称 | 规格 | 数量 | 配套螺钉 | 数量 | 配套螺母 | 数量 | 配套垫片 | 数量 | 螺钉总数 | 螺母总数 | 垫片总数
机箱 | 1 | L型连接块 | 20*20*10 M4螺纹 | 28 | M4*14圆头 | 1 | 无 |  | M4*10*0.5 | 1 | 28 | 0 | 28
 |  | PowerPlane六角铜柱 | M3*30+6 | 16 | M3*20圆头 | 1 | M3*2.4 | 1 | M3*7*0.5 | 2 | 16 | 16 | 32
 |  | HeatSink六角铜柱 | M3*50+6 | 16 | M3*20圆头 | 1 | M3*2.4 | 1 | M3*7*0.5 | 2 | 16 | 16 | 32
 |  | Control六角铜柱 | M3*10+6 | 4 | M3*20圆头 | 1 | M3*2.4 | 1 | M3*7*0.5 | 2 | 4 | 4 | 8
 |  | EMIRemover六角铜柱 | M3*10+6 | 4 | M3*20圆头 | 1 | M3*2.4 | 1 | M3*7*0.5 | 2 | 4 | 4 | 8
 |  | 分线器 | 三进12出 | 1 | M5*22圆头 | 2 | M5*4.0 | 2 | M5*12*0.5 | 4 | 2 | 2 | 4
 |  | 变压器固定 | 无 | 4 | M6*27圆头 | 4 | M6*5.1 | 4 | M4*10*0.5 | 12 | 16 | 16 | 48
 |  | 固线器 | 无 | 1 | M4*20圆头 | 2 | M4*3.1 | 2 | M4*10*0.5 | 4 | 2 | 2 | 4
 |  | 地脚 | 39*39*18 | 6 | M6*22/28圆头 | 1 | M8*6.3 | 1 | M6*12*1 | 2 | 6 | 6 | 12
面板 |  | Xmeter六角铜柱 | M3*16+6 | 16 | 无 | 0 | M3*2.4 | 1 | M3*7*0.5 | 1 | 0 | 16 | 16
 |  | USB接口 |  | 1 | M3*10圆头 | 2 | 无 | 0 | M3*7*0.5 | 2 | 2 | 0 | 2
背板 |  | 散热器网格固定 |  | 4 | M4*14圆头 | 4 | M4*3.1 | 4 | M4*10*0.5 | 8 | 16 | 16 | 32
风扇 |  |  |  | 4 | M3*35平头 | 4 |  | 0 |  | 0 | 16 | 0 | 0
 |  |  |  |  |  |  |  |  | 63

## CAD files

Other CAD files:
Shell/贴纸.dwg
Shell/A3底板.dwg
Shell/A3加强板.dwg
Shell/A3面板.dwg
Shell/A3右侧板.dwg
Shell/A3顶板.dwg
Shell/A3背板.dwg
Shell/A3左侧板.dwg

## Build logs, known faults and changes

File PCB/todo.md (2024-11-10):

## V1.0 ## 
1. [x] DS3 16P原件长度不够
2. [x] 大电流过板Via太小
3. [x] xmeter R2 R6 R10 R11 40k->47K
4. [x] xmeter R13 120k->140
5. [x] powerplane C26 引脚距离不对
6. [x] powerplane C24 引脚距离不对
7. [x] powerplane C10 引脚距离不对
8. [x] powerplane C19 引脚距离不对
9. [x] R28、U6太近
10. [x] U22、U23铁柱焊盘太小
11. [x] C17引脚间距不对
12. [x] 电阻电容二极管焊盘太小
13. [x] TO220三极管焊盘国小
14. [x] 继电器孔略大
15. [x] D11焊盘全都是方的
16. [x] Q7散热会烧坏插座
17. [x] Q3散热烧坏电容
18. [x] 输出泄流电阻和二极管开窗

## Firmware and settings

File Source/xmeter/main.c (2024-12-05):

#include <STC89C5xRC.H>
#include <stdio.h>

#include "debug.h"
#include "com.h"
#include "delay.h"
#include "rom.h"
#include "clock.h"
#include "task.h"
#include "sm.h"
#include "button.h"
#include "beeper.h"
#include "lcd.h"
#include "xmeter.h"
#include "gpio.h"
#include "control.h"
#include "console.h"
#include "version.h"

int main(void)
{
  EA = 1;                                       // enable global interrupts
  gpio_initialize();
  debug_initialize();                           // initialize debug system
  com_initialize(); 
  
  lcd_initialize();
  
	rom_initialize();
  
  lcd_clear();
  lcd_set_string(0,0, "++XMETER V"  __XMETER_VERSION_STRING__ " ++");
  lcd_refresh();
  
  lcd_show_progress(1,1);
  
  clock_initialize();
  task_initialize();
  sm_initialize();
  
  lcd_show_progress(1,1); 
  
  button_initialize();
  beeper_initialize();
  control_initilize();
  console_initilize();
  
  lcd_show_progress(1,2); 
  
  xmeter_initialize();
  
  lcd_show_progress(1,16);
  
	while(1) {
    console_run();
    task_run();
    control_run();
	}
}

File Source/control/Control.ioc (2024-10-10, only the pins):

Mcu.UserName=STM32F103C8Tx
PA10.Signal=USART1_RX
PA11.Signal=USB_DM
PA12.Signal=USB_DP
PA2.Signal=USART2_TX
PA3.Signal=USART2_RX
PA4.GPIO_Label=CHANEL_SEL0
PA4.Signal=GPIO_Output
PA5.GPIO_Label=CHANEL_SEL1
PA5.Signal=GPIO_Output
PA9.Signal=USART1_TX
PC13-TAMPER-RTC.GPIO_Label=DATA_TRANS
PC13-TAMPER-RTC.Signal=GPIO_Output
PC14-OSC32_IN.Signal=RCC_OSC32_IN
PC15-OSC32_OUT.Signal=RCC_OSC32_OUT
PD0-OSC_IN.Signal=RCC_OSC_IN
PD1-OSC_OUT.Signal=RCC_OSC_OUT

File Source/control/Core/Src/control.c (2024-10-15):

#include "control.h"
#include "debug.h"
#include "usart.h"
#include "usbd_cdc_if.h"
#include "gpio.h"

#include <string.h>

#define CONTROL_MSG_WAIT_TIMEOUT_MS 1000 //ms

void control_dump_msg(const char * fmt, const control_msg_t * msg)
{
  uint8_t * p = (uint8_t *)(&(msg->msg_body));
  uint8_t body_len, print_len, i;
	CDBG("%s", fmt);
  CDBG("  msg_header.msg_magic:    %04x", msg->msg_header.msg_magic);  
  CDBG("  msg_header.msg_code:     %02x", msg->msg_header.msg_code);
  CDBG("  msg_header.msg_status:   %02x", msg->msg_header.msg_status);
  CDBG("  msg_header.msg_channel:  %02x", msg->msg_header.msg_channel);
  CDBG("  msg_header.msg_crc:      %02x", msg->msg_header.msg_crc);
  CDBG("  msg_header.msg_body_len: %02x", msg->msg_header.msg_body_len);
  if(msg->msg_header.msg_body_len > 0) {
    CDBG("  msg_body:"); 
    body_len = msg->msg_header.msg_body_len;
    if(body_len > sizeof(control_msg_t) - sizeof(control_msg_header_t)) {
      body_len = sizeof(control_msg_t) - sizeof(control_msg_header_t);
    }
    do {
      print_len = body_len > 16 ? 16 : body_len;
      for(i = 0; i < print_len ; i ++) {
        CDBG_R("%02x ", p[i]);
      }
      CDBG_R("\r\n");
      body_len -= print_len;
      p += print_len;
    }while(body_len);
  }
}

bool control_parse_cmd(control_msg_t * cmd, const uint8_t * buffer, uint32_t len)
{
  control_msg_t * pcmd = (control_msg_t *)buffer;
  
  CDBG("control_parse_cmd: new msg come");
  control_dump_msg("receive cmd", pcmd);
  
  if(!control_verify_msg(pcmd, len)) {
    return false;
  }
  
  memcpy(cmd, pcmd, pcmd->msg_header.msg_body_len + sizeof(control_msg_header_t));
  
  return true;
}

static void control_select_channel(uint8_t channel)
{
  switch(channel)
  {
    case 0:
      HAL_GPIO_WritePin(GPIOA, CHANEL_SEL0_Pin|CHANEL_SEL1_Pin, GPIO_PIN_RESET);
      break;
    case 1:
      HAL_GPIO_WritePin(GPIOA, CHANEL_SEL0_Pin, GPIO_PIN_RESET);
      HAL_GPIO_WritePin(GPIOA, CHANEL_SEL1_Pin, GPIO_PIN_SET);
      break; 
    case 2:
      HAL_GPIO_WritePin(GPIOA, CHANEL_SEL0_Pin, GPIO_PIN_SET);
      HAL_GPIO_WritePin(GPIOA, CHANEL_SEL1_Pin, GPIO_PIN_RESET);
      break; 
    case 3:
      HAL_GPIO_WritePin(GPIOA, CHANEL_SEL0_Pin|CHANEL_SEL1_Pin, GPIO_PIN_SET);
      break;
  }
}

static uint8_t control_hal_error(HAL_StatusTypeDef status)
{
  uint8_t ret;
  
  switch(status){
    case HAL_OK: 
      ret =  CONTROL_MSG_STATUS_SUCCESS;
      break;
    case HAL_ERROR: 
      return CONTROL_MSG_STATUS_ERROR;
      break;
    case HAL_BUSY:
      return CONTROL_MSG_STATUS_BUSY;
      break;
    case HAL_TIMEOUT: 
      return CONTROL_MSG_STATUS_TIMEOUT;
      break; 
    default:
      ret = CONTROL_MSG_STATUS_ERROR;
  }
  return ret;
}

/*
  send msg to channel and get response
*/
void control_relay_cmd(const control_msg_t * cmd, control_msg_t * res)
{
  HAL_StatusTypeDef status;
  uint8_t error_code;
  
  control_select_channel(cmd->msg_header.msg_channel);
  // control_select_channel(0);
  
  memset((uint8_t *)res, 0, sizeof(control_msg_t));
  
  status = USART2_Receive_IT((uint8_t *)res, sizeof(control_msg_t));
  if(HAL_OK != status) {
    error_code = control_hal_error(status);
    CERR("control_relay_cmd: USART2_Receive_IT failed %d", status);
    goto err;
  }
  
  control_dump_msg("control_relay_cmd send msg", cmd);
  
  status = USART2_Transmit((uint8_t *)cmd, sizeof(control_msg_t));
  
  if(HAL_OK != status) {
    error_code = control_hal_error(status);
    CERR("control_relay_cmd: USART2_Transmit failed %d", status);
    goto err;
  }
  
  status = USART2_Receive_Wait(CONTROL_MSG_WAIT_TIMEOUT_MS);
  
  if(HAL_OK != status) {
    error_code = control_hal_error(status);
    CERR("control_relay_cmd: USART2_Receive_Wait failed %d", status);
    goto err;
  }
  
  control_dump_msg("control_relay_cmd recv res", res);
  
  if(!control_verify_msg(res, sizeof(control_msg_t)) || (res->msg_header.msg_code & 0x80) == 0) {
    error_code = CONTROL_MSG_STATUS_PROTO;
    CERR("control_relay_cmd: invalid response");
    goto err;
  }
  
  if((cmd->msg_header.msg_code & 0x7F) != (res->msg_header.msg_code & 0x7F)) {
    error_code = CONTROL_MSG_STATUS_PROTO;
    CERR("control_relay_cmd: cmd & response mis-match");
    goto err;
  }
  
  return;
  
err:  
  memcpy(res, cmd, sizeof(control_msg_t));
  res->msg_header.msg_code |= 0x80;
  res->msg_header.msg_status = error_code;
  res->msg_header.msg_body_len = 0;
  control_fill_msg_crc(res);
}

/*
  send response to computer
*/

bool control_send_response(const control_msg_t * res)
{
  uint8_t status = CDC_Transmit_FS((uint8_t *)res, sizeof(control_msg_t));
	
  if(status != USBD_OK) {
    CERR("CDC_Transmit_FS failed: %d", status);
  }
  
  return status == USBD_OK;
}

void control_send_heatbeat(control_msg_t * cmd, control_msg_t * res, uint8_t index)
{
  CDBG("control_send_heatbeat to channel %d", index);
  memset(cmd, 0, sizeof(control_msg_t));
  memset(res, 0, sizeof(control_msg_t));
  
  cmd->msg_header.msg_body_len = 0;
  cmd->msg_header.msg_channel  = 0;  
  cmd->msg_header.msg_code     = CONTROL_MSG_CODE_HEATBEAT;  
  cmd->msg_header.msg_crc      = 0; 
  cmd->msg_header.msg_magic    = CONTROL_MSG_MAGIC_CODE;  
  cmd->msg_header.msg_status   = CONTROL_MSG_STATUS_SUCCESS;
  
  cmd->msg_header.msg_channel  = index; 
  control_fill_msg_crc(cmd);
  control_relay_cmd(cmd, res);
}

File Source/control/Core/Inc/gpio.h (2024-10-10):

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
/* Define to prevent recursive inclusion -------------------------------------*/
#ifndef __GPIO_H__
#define __GPIO_H__

#ifdef __cplusplus
extern "C" {
#endif

/* Includes ------------------------------------------------------------------*/
#include "main.h"

/* USER CODE BEGIN Private defines */
#define DATA_TRANS_Pin GPIO_PIN_13
#define DATA_TRANS_GPIO_Port GPIOC
#define CHANEL_SEL0_Pin GPIO_PIN_4
#define CHANEL_SEL1_Pin GPIO_PIN_5
#define CHANEL_GPIO_Port GPIOA
/* USER CODE END Private defines */

void MX_GPIO_Init(void);

#ifdef __cplusplus
}
#endif
#endif /*__ GPIO_H__ */

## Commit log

2024-10-15 temp save
    [CNCPowerSupply.PcbLib, CNCPowerSupply.SchLib, Control.SchDoc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]
2024-10-19 sch finished
    [Control.PrjPcb, Control.SchDoc, PowerPlane.SchDoc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]
2024-10-19 bug fix
    [Control.SchDoc]
2024-10-21 开始画外壳了
    [A3底板.dwg, A3面板.dwg]
2024-10-22 面板和底板画完了
    [A3底板.dwg, A3面板.dwg]
2024-10-24 shell almost finished
    [A3加强板.dwg, A3右侧板.dwg, A3左侧板.dwg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]
2024-10-26 xmeter pcb finished
    [A3面板.dwg, Control.SchDoc, HeatSink.PrjPcb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]
2024-10-28 xmeter pcb done
    [Control.SchDoc, HeatSink.SchDoc, PowerPlane.PcbDoc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]
2024-10-28 开始画PowerPlane了
    [PowerPlane.SchDoc]
2024-10-31 powerplane 完成
    [PowerPlane - 副本.PcbDoc, PowerPlane.PcbDoc, PowerPlane.PrjPcb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]
2024-11-01 powerplane complete
    [PowerPlane - 副本.PcbDoc, PowerPlane.PcbDoc, PowerPlane.SchDoc]
2024-11-01 all pcb done！
    [Control - 副本.PcbDoc, Control.PcbDoc, Control.PrjPcb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]
2024-11-06 all done
    [A3加强板.dwg, A3右侧板.dwg, A3左侧板.dwg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]
2024-11-09 xmeter 硬件调试通过
    [PowerPlane.PcbDoc, PowerPlane.PrjPcb, PowerPlane.SchDoc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]
2024-11-13 新版本xmeter完成
    [HeatSink.PcbDoc, HeatSink.SchDoc, PowerPlane.SchDoc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]
2024-11-14 新powerplane完成！
    [HeatSink.PcbDoc, PowerPlane - 副本.PcbDoc, PowerPlane.PcbDoc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]
2024-11-16 bugfix，修改了control的尺寸
    [A3右侧板.dwg, A3左侧板.dwg, Control - 副本.PcbDoc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]
2024-11-19 xmeter代码根据硬件改成高端
    [A3右侧板.dwg, A3底板.dwg, A3背板.dwg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]
2024-11-22 EMI Remover finished
    [A3底板.dwg, EMIRemover.PcbDoc, EMIRemover.PrjPcb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]
2024-11-25 fix all bomdoc
    [Control.PrjPcb, EMIRemover.PrjPcb, HeatSink.PrjPcb]
2024-11-26 powerplane&heatsink调通
    [PowerPlane.PcbDoc, PowerPlane.SchDoc]
2024-12-03 XMeter PCB 1.5 and Console
    [PowerPlane.PcbDoc, PowerPlane.SchDoc, XMeter.PcbDoc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]
2024-12-04 bug fix of xmeter console
    [console.c, xmeter.c]
2024-12-05 bug fix！
2024-12-05 rom从256K到512K
    [A3加强板.dwg, A3右侧板.dwg, A3左侧板.dwg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]
2024-12-06 外壳检查，bug修正
    [A3加强板.dwg, A3右侧板.dwg, A3底板.dwg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]
2024-12-07 bugfix off shell
    [A3加强板.dwg, A3右侧板.dwg, A3左侧板.dwg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]
2024-12-09 add ability of calibrate adc and dac directly
2024-12-11 添加了离线调零机制，可以结合console一起用
2024-12-28 pcb bugfix
    [A3加强板.dwg, A3底板.dwg, A3面板.dwg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]
2025-01-02 底板上少两个孔
    [A3底板.dwg, FrontPanel.PrjPcb, RarePanel.PrjPcb]

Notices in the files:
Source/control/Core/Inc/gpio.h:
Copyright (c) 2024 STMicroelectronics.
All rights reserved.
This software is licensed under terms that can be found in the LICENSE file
